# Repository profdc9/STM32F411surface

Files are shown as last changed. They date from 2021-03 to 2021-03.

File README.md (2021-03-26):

# STM32surface
This is a Bluepill-compatible devboard for the STM32F411CEU6 microcontroller.
It uses 0805 surface mount parts and a few through hole parts that can be easily obtained as
generic components.  It is intended to be an alternative should the 
should the STM32F411CE6 Bluepill not be available.
The layout is somewhat optimized to be RFI resistant given it is a two-layer board
This material is copyrighted by Daniel Marks (KW4TI) and licensed under
the Creative Commons License CC-BY-SA 4.0.  Software is copyrighted using the zlib
open-source license.

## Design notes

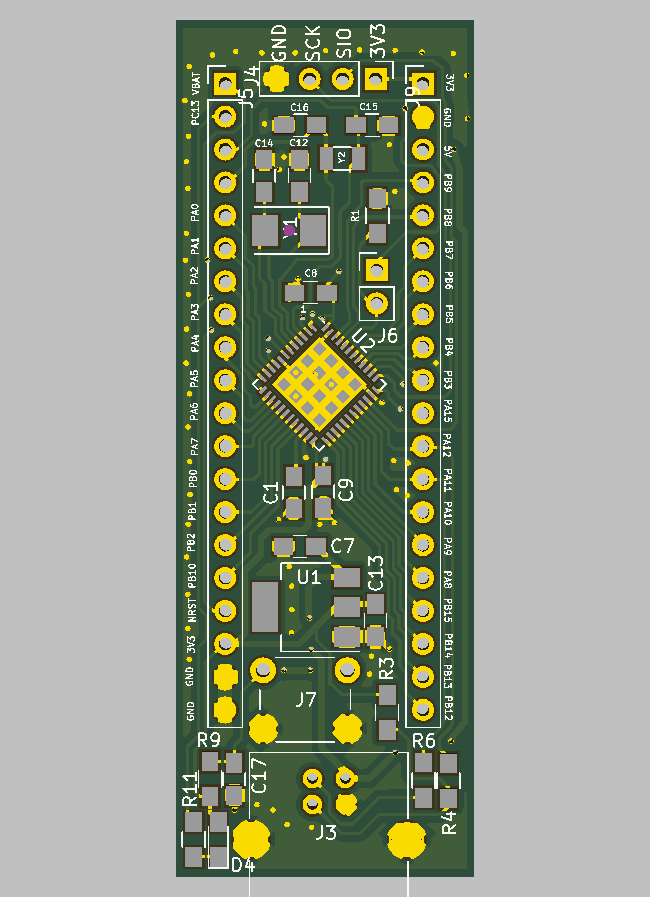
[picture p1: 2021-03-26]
STM32surface.png

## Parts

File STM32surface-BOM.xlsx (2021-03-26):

Comment | Designator | Footprint | LCSC
4.7 uF | C1 | Capacitors_SMD:C_0805_HandSoldering | C1779
20 pF | C12,C14,C15,C16 | Capacitors_SMD:C_0805_HandSoldering | C1804
1 uF | C13,C7 | Capacitors_SMD:C_0805_HandSoldering | C28323
10 nF | C17 | Capacitors_SMD:C_0805_HandSoldering | C1710
0.1 uF | C8,C9 | Capacitors_SMD:C_0805_HandSoldering | C49678
LED | D4 | LEDs:LED_0805_HandSoldering | C2296
USB_B | J3 | Connectors:USB_B
Conn_01x04 | J4 | Pin_Headers:Pin_Header_Straight_1x04_Pitch2.54mm
Conn_01x20 | J5,J9 | Pin_Headers:Pin_Header_Straight_1x20_Pitch2.54mm
Conn_01x02 | J6 | Pin_Headers:Pin_Header_Straight_1x02_Pitch2.54mm
Conn_01x02 | J7 | Buttons_Switches_THT:SW_PUSH_6mm
470R | R11 | Resistors_SMD:R_0805_HandSoldering | C17710
1.5k | R3,R9,R1 | Resistors_SMD:R_0805_HandSoldering | C4310
22R | R4,R6 | Resistors_SMD:R_0805_HandSoldering | C17561
AMS1117-3V3 | U1 | TO_SOT_Packages_SMD:SOT-223 | C6186
STM32F411CEU6 | U2 | Housings_DFN_QFN:QFN-48-1EP_7x7mm_Pitch0.5mm | C60420
8 MHz | Y1 | Crystals:Crystal_SMD_5032-2pin_5.0x3.2mm | C115962
Crystal | Y2 | Crystals:Crystal_SMD_3215-2pin_3.2x1.5mm | C32346

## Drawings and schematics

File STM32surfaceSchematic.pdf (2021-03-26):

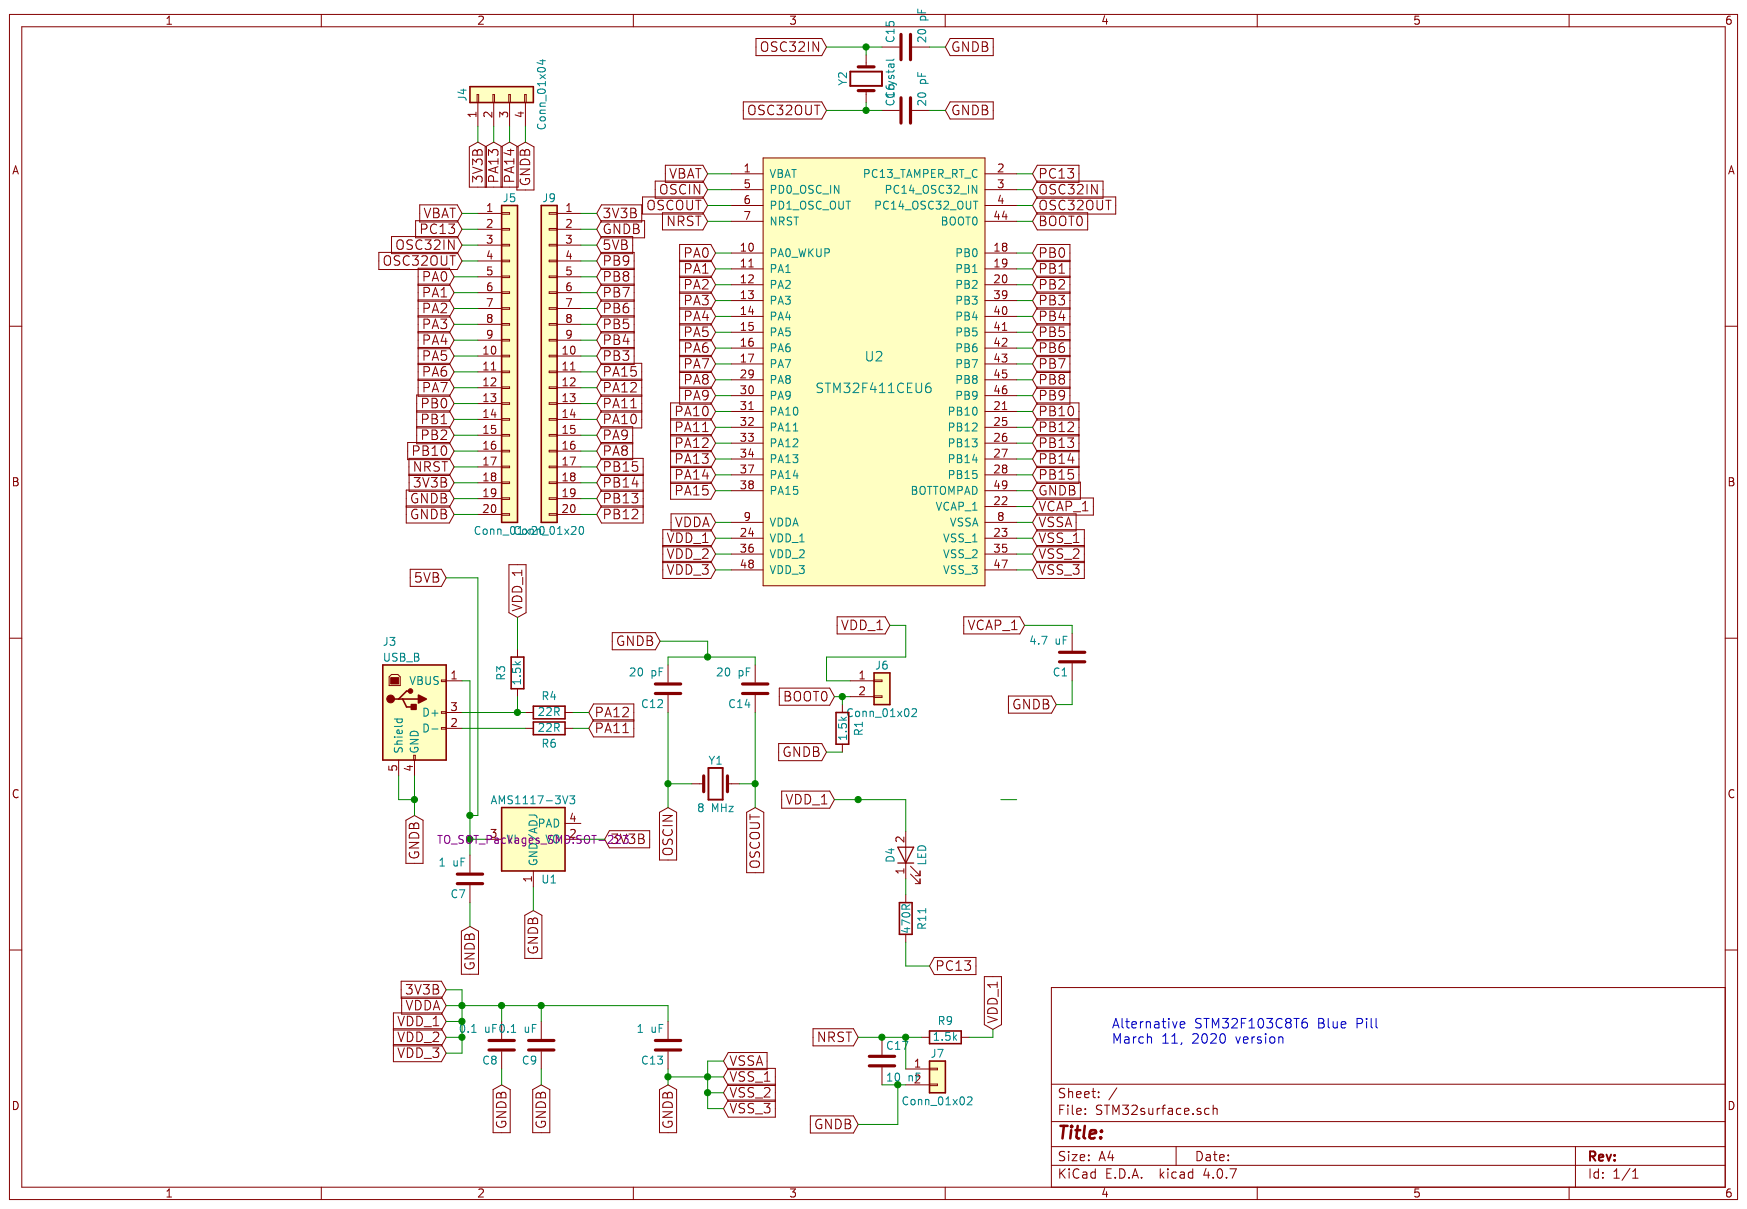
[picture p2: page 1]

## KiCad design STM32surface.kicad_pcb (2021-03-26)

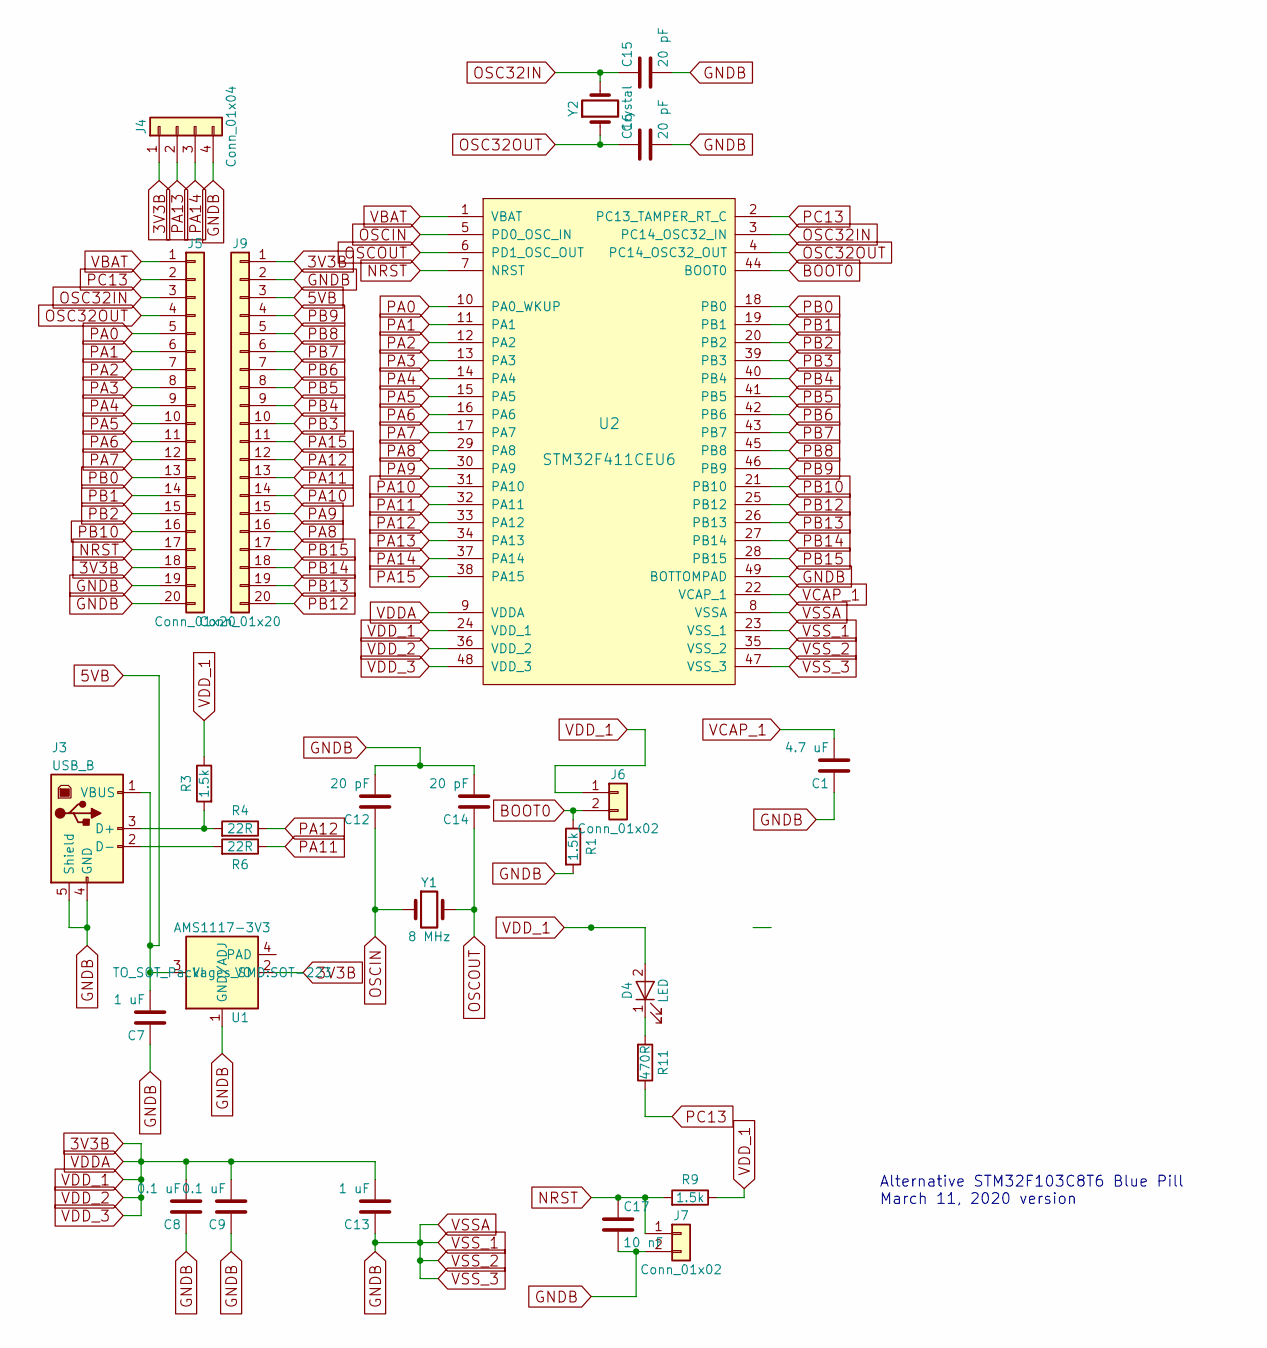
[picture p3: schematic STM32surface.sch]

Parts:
C1: 4.7 uF; C_0805_HandSoldering; LCSC C1779
C7, C13: 1 uF; C_0805_HandSoldering; LCSC C28323
C8, C9: 0.1 uF; C_0805_HandSoldering; LCSC C49678
C12, C14, C15, C16: 20 pF; C_0805_HandSoldering; LCSC C1804
C17: 10 nF; C_0805_HandSoldering; LCSC C1710
D4: LED; LED_0805_HandSoldering; LCSC C2296
J3: USB_B
J4: Conn_01x04; Pin_Header_Straight_1x04_Pitch2.54mm
J5, J9: Conn_01x20; Pin_Header_Straight_1x20_Pitch2.54mm
J6: Conn_01x02; Pin_Header_Straight_1x02_Pitch2.54mm
J7: Conn_01x02; SW_PUSH_6mm
R1, R3, R9: 1.5k; R_0805_HandSoldering; LCSC C4310
R4, R6: 22R; R_0805_HandSoldering; LCSC C17561
R11: 470R; R_0805_HandSoldering; LCSC C17710
U1: AMS1117-3V3; SOT-223; MPN LM1117; LCSC C6186
U2: STM32F411CEU6; QFN-48-1EP_7x7mm_Pitch0.5mm; LCSC C60420
Y1: 8 MHz; Crystal_SMD_5032-2pin_5.0x3.2mm; LCSC C115962
Y2: Crystal; Crystal_SMD_3215-2pin_3.2x1.5mm; LCSC C32346

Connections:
3V3B: C8.2, C9.2, C13.2, D4.2 (A), J4.1, J5.18, J6.1, J9.1, R3.1, R9.1, U1.2 (VO), U2.9 (VDDA), U2.24 (VDD_1), U2.36 (VDD_2), U2.48 (VDD_3)
5VB: C7.2, J3.1 (VBUS), J9.3, U1.3 (VI)
BOOT0: J6.2, R1.1, U2.44 (BOOT0)
GNDB: C1.1, C7.1, C8.1, C9.1, C12.2, C13.1, C14.2, C15.2, C16.2, C17.2, J3.4 (GND), J3.5 (Shield), J4.4, J5.19, J5.20, J7.2, J9.2, R1.2, U1.1 (GND/ADJ), U2.8 (VSSA), U2.23 (VSS_1), U2.35 (VSS_2), U2.47 (VSS_3), U2.49 (BOTTOMPAD)
NRST: C17.1, J5.17, J7.1, R9.2, U2.7 (NRST)
unnamed: D4.1 (K), R11.2
unnamed: J3.2 (D-), R6.2
unnamed: J3.3 (D+), R3.2, R4.2
OSC32IN: C15.1, J5.3, U2.3 (PC14_OSC32_IN), Y2.2
OSC32OUT: C16.1, J5.4, U2.4 (PC14_OSC32_OUT), Y2.1
OSCIN: C12.1, U2.5 (PD0_OSC_IN), Y1.1
OSCOUT: C14.1, U2.6 (PD1_OSC_OUT), Y1.2
PA0: J5.5, U2.10 (PA0_WKUP)
PA1: J5.6, U2.11 (PA1)
PA2: J5.7, U2.12 (PA2)
PA3: J5.8, U2.13 (PA3)
PA4: J5.9, U2.14 (PA4)
PA5: J5.10, U2.15 (PA5)
PA6: J5.11, U2.16 (PA6)
PA7: J5.12, U2.17 (PA7)
PA8: J9.16, U2.29 (PA8)
PA9: J9.15, U2.30 (PA9)
PA10: J9.14, U2.31 (PA10)
PA11: J9.13, R6.1, U2.32 (PA11)
PA12: J9.12, R4.1, U2.33 (PA12)
PA13: J4.2, U2.34 (PA13)
PA14: J4.3, U2.37 (PA14)
PA15: J9.11, U2.38 (PA15)
PB0: J5.13, U2.18 (PB0)
PB1: J5.14, U2.19 (PB1)
PB2: J5.15, U2.20 (PB2)
PB3: J9.10, U2.39 (PB3)
PB4: J9.9, U2.40 (PB4)
PB5: J9.8, U2.41 (PB5)
PB6: J9.7, U2.42 (PB6)
PB7: J9.6, U2.43 (PB7)
PB8: J9.5, U2.45 (PB8)
PB9: J9.4, U2.46 (PB9)
PB10: J5.16, U2.21 (PB10)
PB12: J9.20, U2.25 (PB12)
PB13: J9.19, U2.26 (PB13)
PB14: J9.18, U2.27 (PB14)
PB15: J9.17, U2.28 (PB15)
PC13: J5.2, R11.1, U2.2 (PC13_TAMPER_RT_C)
VBAT: J5.1, U2.1 (VBAT)
VCAP_1: C1.2, U2.22 (VCAP_1)

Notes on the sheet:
Alternative STM32F103C8T6 Blue Pill March 11, 2020 version

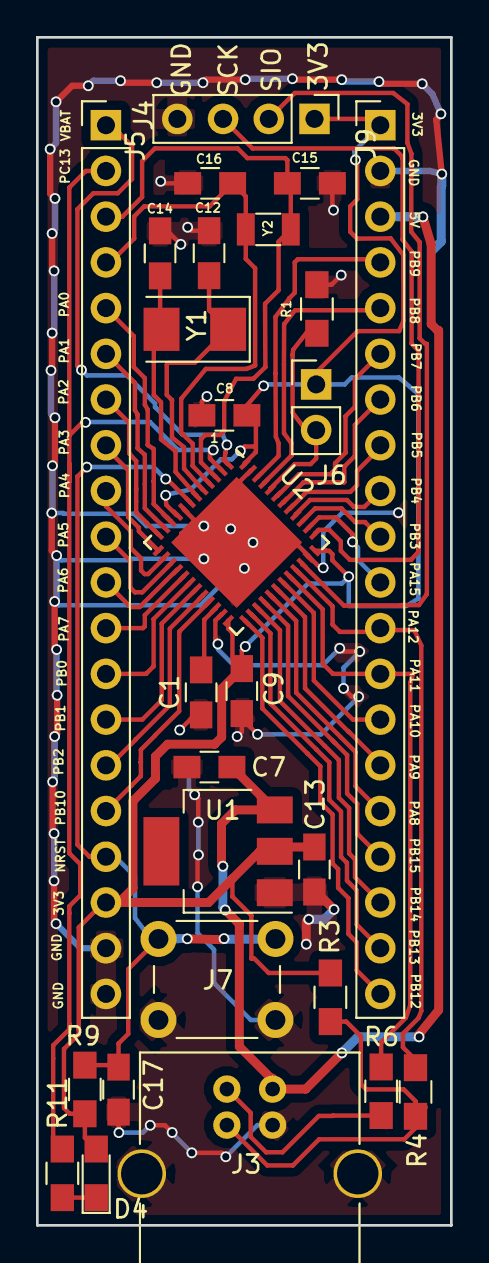
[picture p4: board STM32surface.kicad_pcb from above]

Board: 2 copper layers, 23.0 x 66.0 mm, 27 parts (0 on the bottom side), 46 nets.
